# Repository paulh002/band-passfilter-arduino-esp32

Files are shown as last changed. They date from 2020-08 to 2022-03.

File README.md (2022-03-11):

# band-passfilter-arduino-esp32
ESP32 managed HF bandpass filter
The PCB supports 4 7 order bandpass filters. The filters are switched using AS169 gasfet switches.
The filters can be designed using elsie software of tonnesoftware (until 7th order free)  http://tonnesoftware.com/elsie.html
The AS169 are switched by using I2C 2x PCF8574A. The boards can be cascaded.
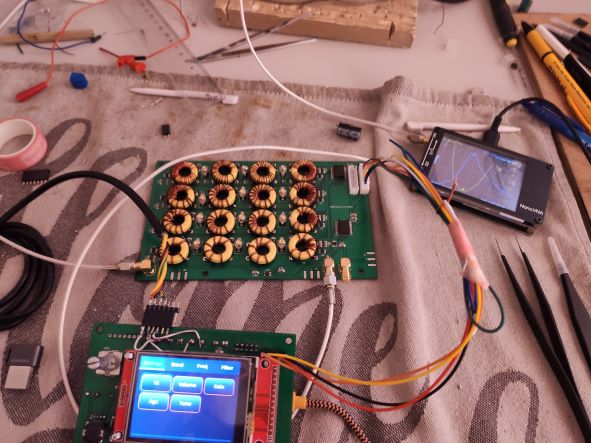
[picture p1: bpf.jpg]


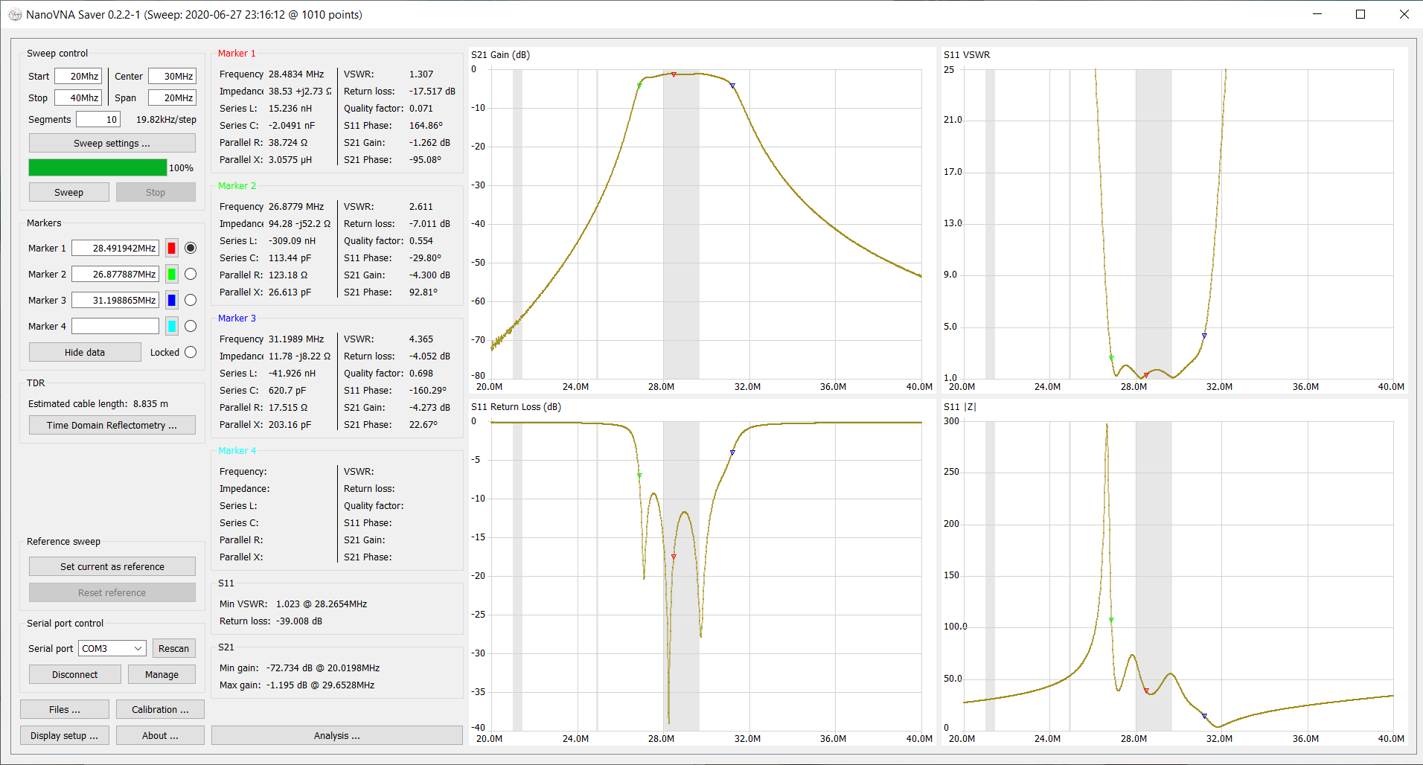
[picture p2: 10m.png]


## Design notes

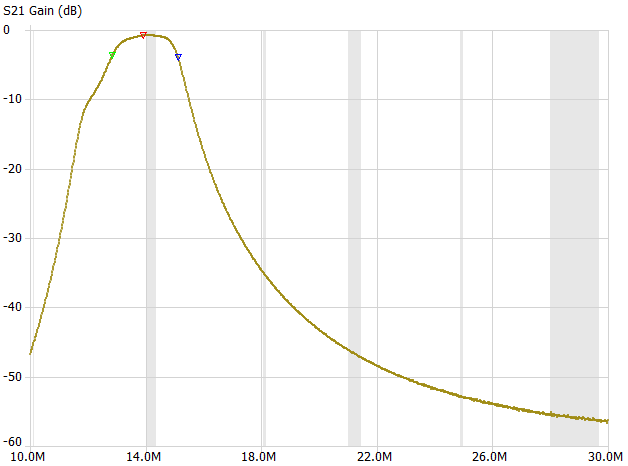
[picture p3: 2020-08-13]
20m bpf.png

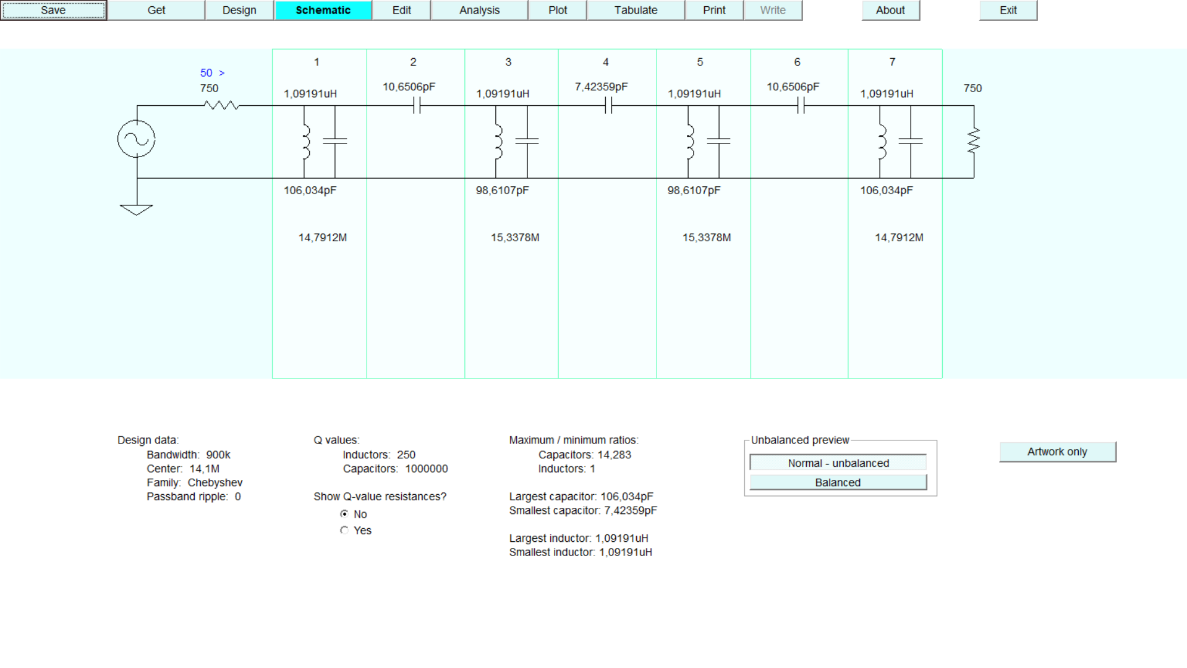
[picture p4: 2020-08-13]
20m.png

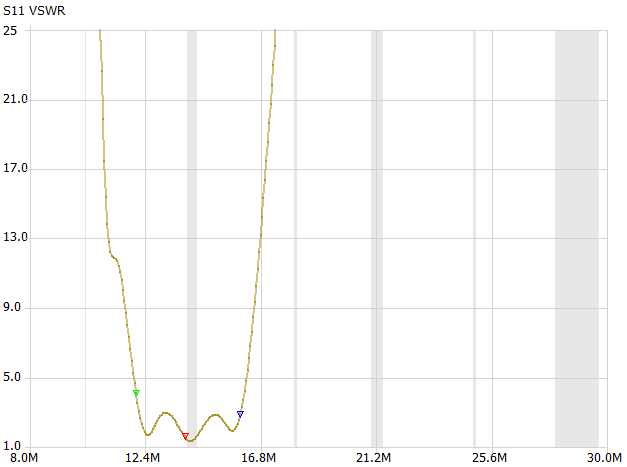
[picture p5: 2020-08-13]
20m vswr.png

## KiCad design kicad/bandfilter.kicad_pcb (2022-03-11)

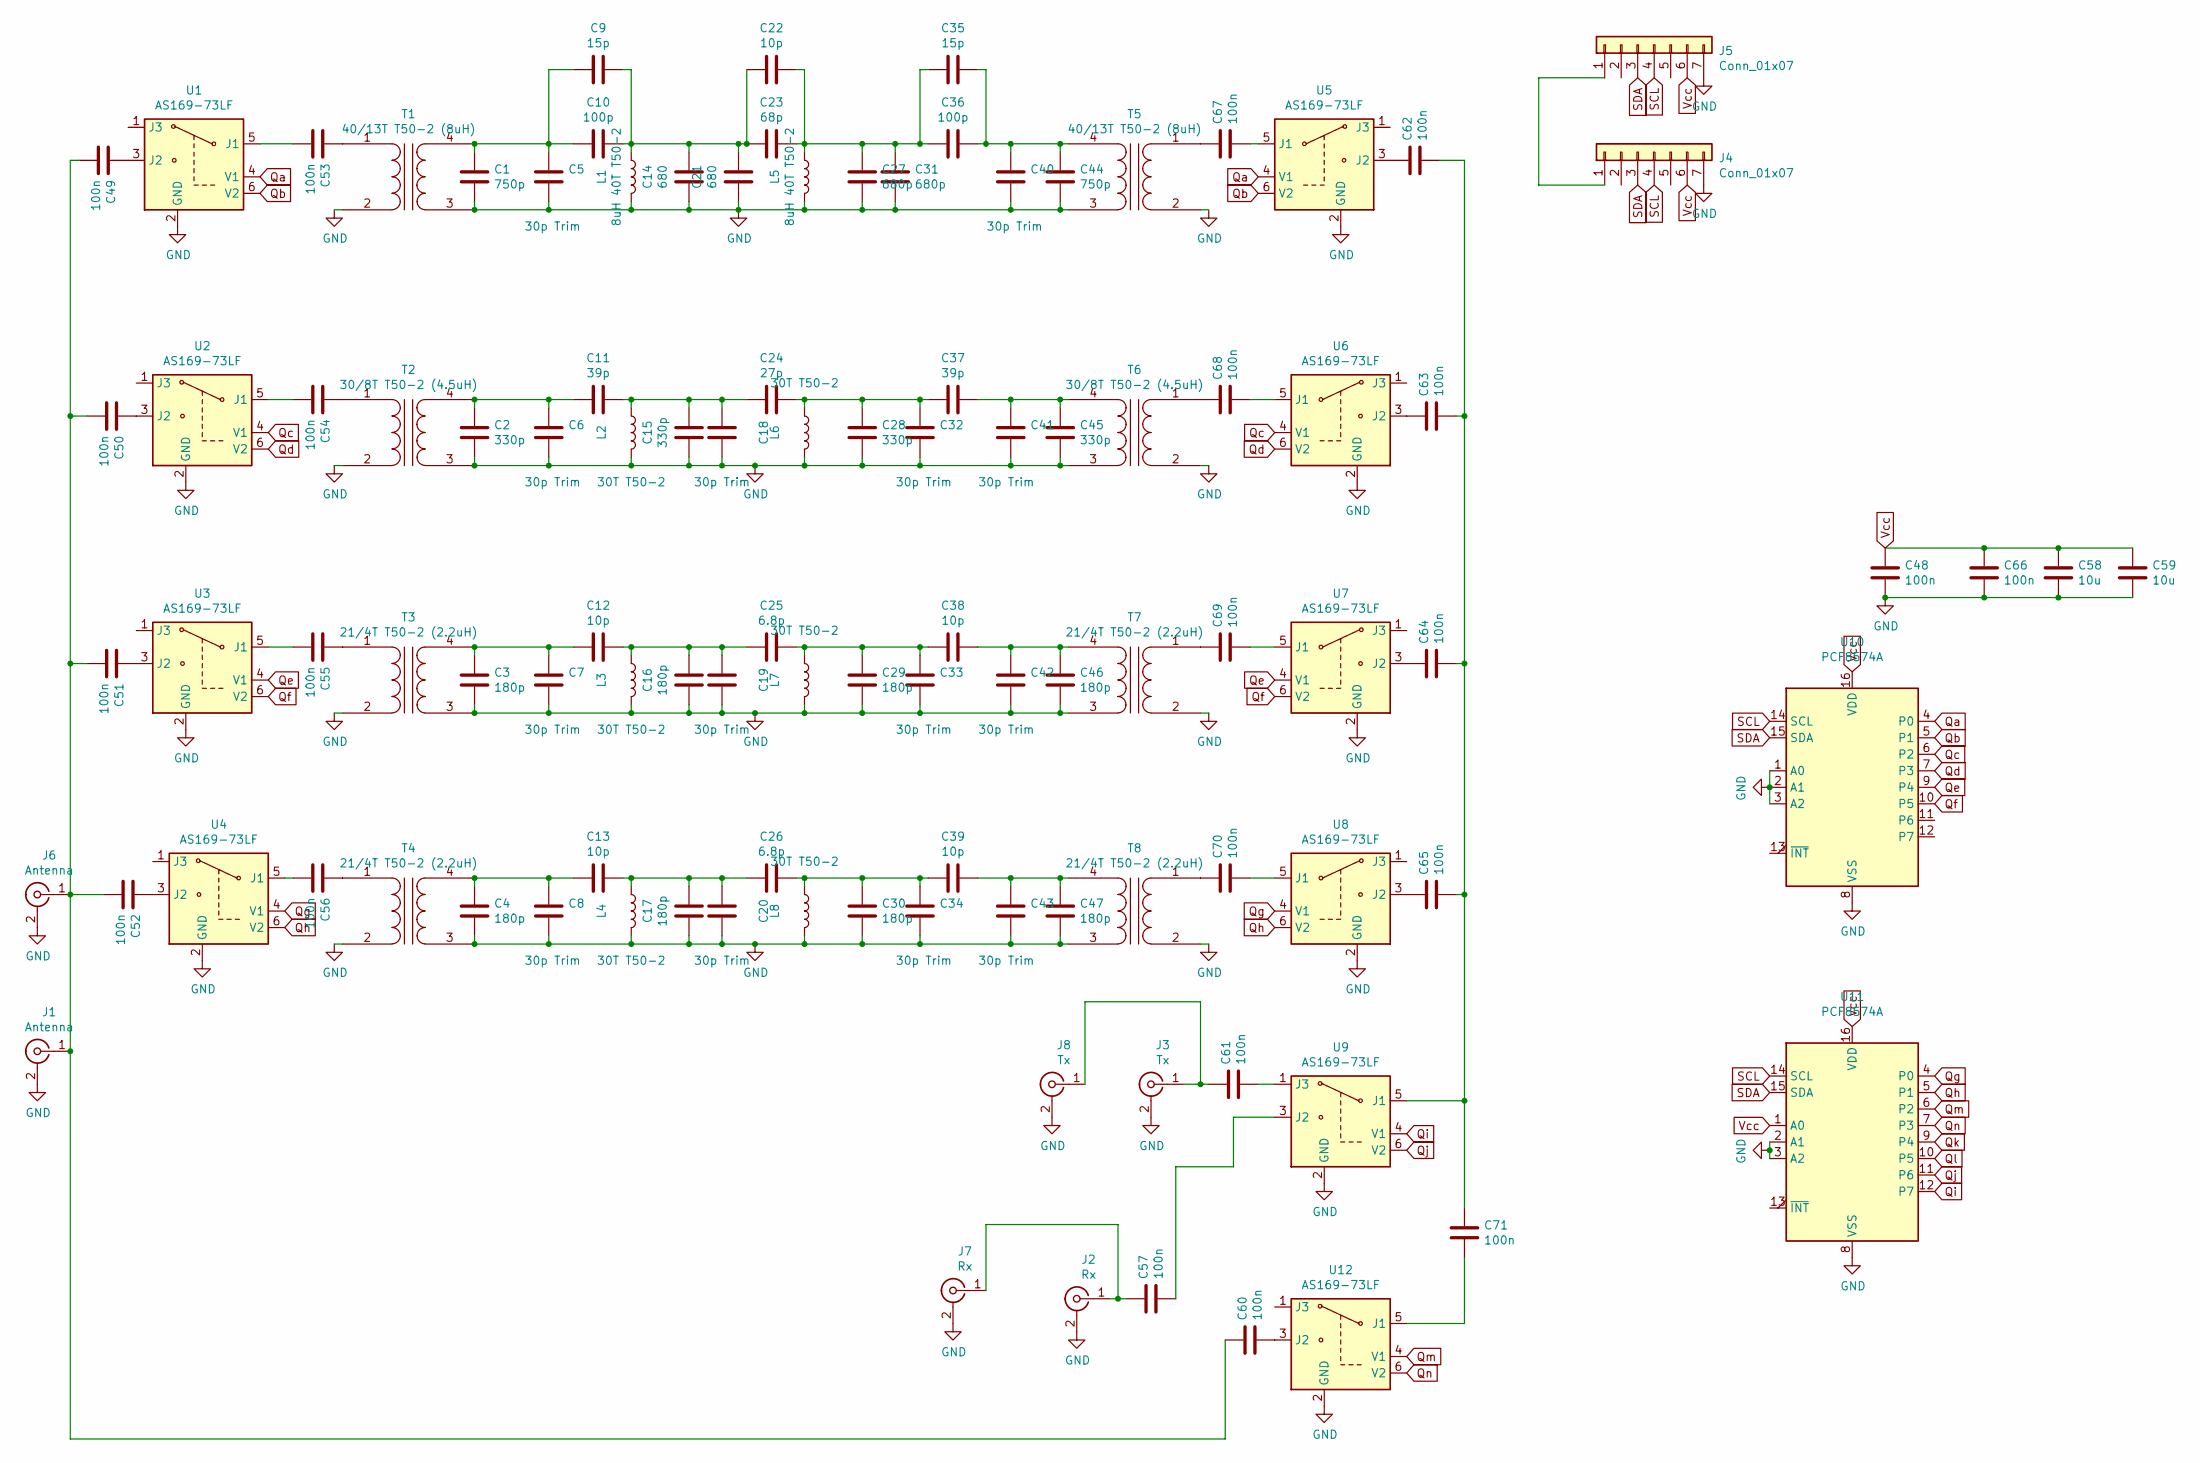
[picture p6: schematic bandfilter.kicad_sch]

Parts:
C1: 750p; C_0805_2012Metric_Pad1.15x1.40mm_HandSolder
C2, C15, C28: 330p; C_0805_2012Metric_Pad1.15x1.40mm_HandSolder
C3, C4, C16, C17, C29, C30: 180p; C_0805_2012Metric_Pad1.15x1.40mm_HandSolder
C5, C6, C7, C8, C18, C19, C20, C32, C33, C34: 30p Trim; C_0805_2012Metric_Pad1.15x1.40mm_HandSolder
C9, C35: 15p; C_Disc_D9.0mm_W5.0mm_P5.00mm
C10, C36: 100p; C_0805_2012Metric_Pad1.15x1.40mm_HandSolder
C11, C37: 39p; C_Disc_D9.0mm_W5.0mm_P5.00mm
C12, C13, C22, C38, C39: 10p; C_Disc_D9.0mm_W5.0mm_P5.00mm
C14, C21: 680; C_0805_2012Metric_Pad1.15x1.40mm_HandSolder
C23: 68p; C_0805_2012Metric_Pad1.15x1.40mm_HandSolder
C24: 27p; C_Disc_D9.0mm_W5.0mm_P5.00mm
C25, C26: 6.8p; C_Disc_D9.0mm_W5.0mm_P5.00mm
C27, C31: 680p; C_0805_2012Metric_Pad1.15x1.40mm_HandSolder
C40, C41, C42, C43: 30p Trim; C_0805_2012Metric
C44: 750p; C_0805_2012Metric
C45: 330p; C_0805_2012Metric
C46, C47: 180p; C_0805_2012Metric
C48, C49, C50, C51, C52, C53, C54, C55, C56, C57, C60, C61, C62, C63, C64, C65, C66, C67, C68, C69, C70, C71: 100n; C_1206_3216Metric_Pad1.42x1.75mm_HandSolder
C58, C59: 10u; C_1206_3216Metric_Pad1.42x1.75mm_HandSolder
J1: Antenna; SMA_Amphenol_132134_Vertical
J2: Rx; SMA_Amphenol_132134_Vertical
J3: Tx; SMA_Amphenol_132134_Vertical
J4, J5: Conn_01x07; PinSocket_1x07_P2.54mm_Vertical
J6: Antenna; SMA_Amphenol_132289_EdgeMount
J7: Rx; SMA_Amphenol_132289_EdgeMount
J8: Tx; SMA_Amphenol_132289_EdgeMount
L1, L5: 8uH 40T T50-2; Transformer_Toroid_Horizontal_D14.0mm_Amidon-T50
L2, L3, L4, L6, L7, L8: 30T T50-2; Transformer_Toroid_Horizontal_D14.0mm_Amidon-T50
T1, T5: 40/13T T50-2 (8uH); Transformer_Toroid_Horizontal_D14.0mm_Amidon-T50
T2, T6: 30/8T T50-2 (4.5uH); Transformer_Toroid_Horizontal_D14.0mm_Amidon-T50
T3, T4, T7, T8: 21/4T T50-2 (2.2uH); Transformer_Toroid_Horizontal_D14.0mm_Amidon-T50
U1, U2, U3, U4, U5, U6, U7, U8, U9, U12: AS169-73LF; SOT-23-6_Handsoldering
U10, U11: PCF8574A; SOP-16_7.5x10.4mm_P1.27mm

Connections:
unnamed: C1.2, C5.2, C9.2, C10.2, T1.4 (SB)
unnamed: C9.1, C10.1, C14.1, C21.1, C22.2, C23.2, L1.1
unnamed: C11.1, C15.1, C18.2, C24.2, L2.1
unnamed: C2.2, C6.2, C11.2, T2.4 (SB)
unnamed: C12.1, C16.1, C19.2, C25.2, L3.1
unnamed: C3.2, C7.2, C12.2, T3.4 (SB)
unnamed: C13.1, C17.1, C20.2, C26.2, L4.1
unnamed: C4.2, C8.2, C13.2, T4.4 (SB)
unnamed: C22.1, C23.1, C27.2, C31.2, C35.2, C36.2, L5.1
unnamed: C24.1, C28.2, C32.2, C37.2, L6.1
unnamed: C25.1, C29.2, C33.2, C38.2, L7.1
unnamed: C26.1, C30.2, C34.2, C39.2, L8.1
unnamed: C35.1, C36.1, C40.2, C44.2, T5.4 (SB)
unnamed: C37.1, C41.2, C45.2, T6.4 (SB)
unnamed: C38.1, C42.2, C46.2, T7.4 (SB)
unnamed: C39.1, C43.2, C47.2, T8.4 (SB)
unnamed: C49.1, C50.1, C51.1, C52.1, C60.2, J1.1 (In), J6.1 (In)
unnamed: C49.2, U1.3 (J2)
unnamed: C50.2, U2.3 (J2)
unnamed: C51.2, U3.3 (J2)
unnamed: C52.2, U4.3 (J2)
unnamed: C53.1, U1.5 (J1)
unnamed: C53.2, T1.1 (AA)
unnamed: C54.1, U2.5 (J1)
unnamed: C54.2, T2.1 (AA)
unnamed: C55.1, U3.5 (J1)
unnamed: C55.2, T3.1 (AA)
unnamed: C56.1, U4.5 (J1)
unnamed: C56.2, T4.1 (AA)
unnamed: C57.1, U9.3 (J2)
unnamed: C57.2, J2.1 (In), J7.1 (In)
unnamed: C60.1, U12.3 (J2)
unnamed: C61.1, U9.1 (J3)
unnamed: C61.2, J3.1 (In), J8.1 (In)
unnamed: C62.1, C63.1, C64.1, C65.1, C71.2, U9.5 (J1)
unnamed: C62.2, U5.3 (J2)
unnamed: C63.2, U6.3 (J2)
unnamed: C64.2, U7.3 (J2)
unnamed: C65.2, U8.3 (J2)
unnamed: C67.1, U5.5 (J1)
unnamed: C67.2, T5.1 (AA)
unnamed: C68.1, U6.5 (J1)
unnamed: C68.2, T6.1 (AA)
unnamed: C69.1, U7.5 (J1)
unnamed: C69.2, T7.1 (AA)
unnamed: C70.1, U8.5 (J1)
unnamed: C70.2, T8.1 (AA)
unnamed: C71.1, U12.5 (J1)
unnamed: J4.1, J5.1
Qa: U1.4 (V1), U5.4 (V1), U10.4 (P0)
Qb: U1.6 (V2), U5.6 (V2), U10.5 (P1)
Qc: U2.4 (V1), U6.4 (V1), U10.6 (P2)
Qd: U2.6 (V2), U6.6 (V2), U10.7 (P3)
Qe: U3.4 (V1), U7.4 (V1), U10.9 (P4)
Qf: U3.6 (V2), U7.6 (V2), U10.10 (P5)
Qg: U4.4 (V1), U8.4 (V1), U11.4 (P0)
Qh: U4.6 (V2), U8.6 (V2), U11.5 (P1)
Qi: U9.4 (V1), U11.12 (P7)
Qj: U9.6 (V2), U11.11 (P6)
Qk: U11.9 (P4)
Ql: U11.10 (P5)
Qm: U11.6 (P2), U12.4 (V1)
Qn: U11.7 (P3), U12.6 (V2)
SCL: J4.4, J5.4, U10.14 (SCL), U11.14 (SCL)
SDA: J4.3, J5.3, U10.15 (SDA), U11.15 (SDA)
Vcc: C48.2, C58.2, C59.2, C66.2, J4.6, J5.6, U10.16 (VDD), U11.1 (A0), U11.16 (VDD)

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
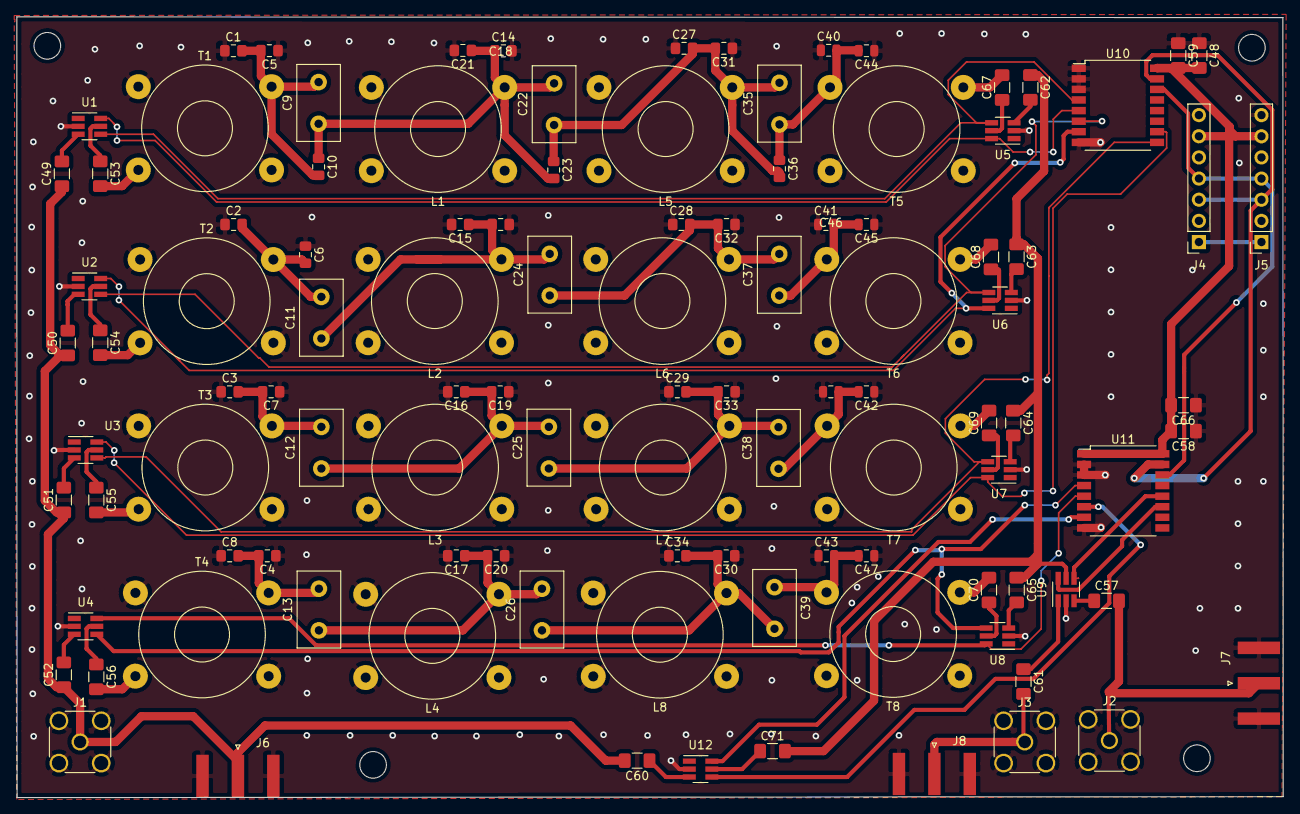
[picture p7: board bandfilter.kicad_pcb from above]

Board: 2 copper layers, 152.0 x 93.7 mm, 111 parts (0 on the bottom side), 65 nets.

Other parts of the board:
 : MountingHole_3.2mm_M3
 #2,  #3,  #4: MountingHole_3.2mm_M3
